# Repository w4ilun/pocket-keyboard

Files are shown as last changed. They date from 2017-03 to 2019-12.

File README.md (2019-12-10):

## Pocket Keyboard

First attempt at building a keyboard from scratch

* PCB Design and Fabrication - EasyEDA + Seeed
* EasyEDA Project [Link](https://easyeda.com/w4ilun/Pocket_Key-5001400dc132468eae7bc688ea3f74ed)
* Firmware - [TMK](https://github.com/tmk/tmk_keyboard)

Assembled

### Top Layer
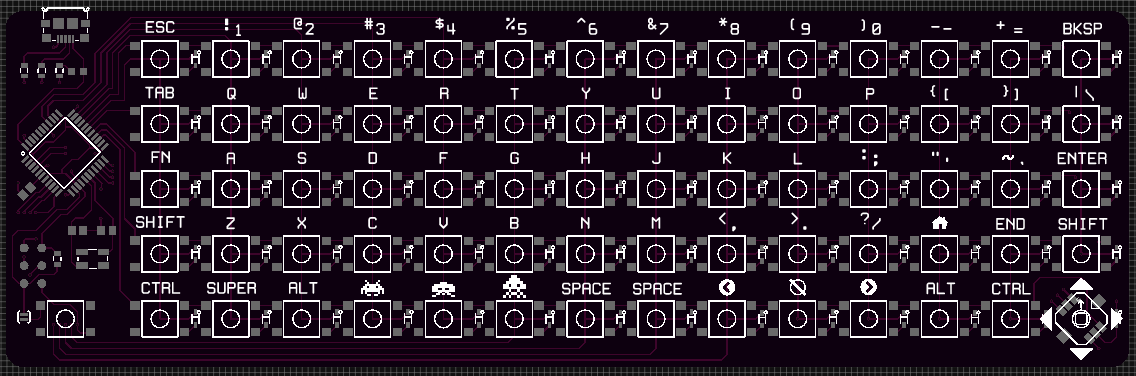
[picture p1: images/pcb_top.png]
Top Layer


### Bottom Layer
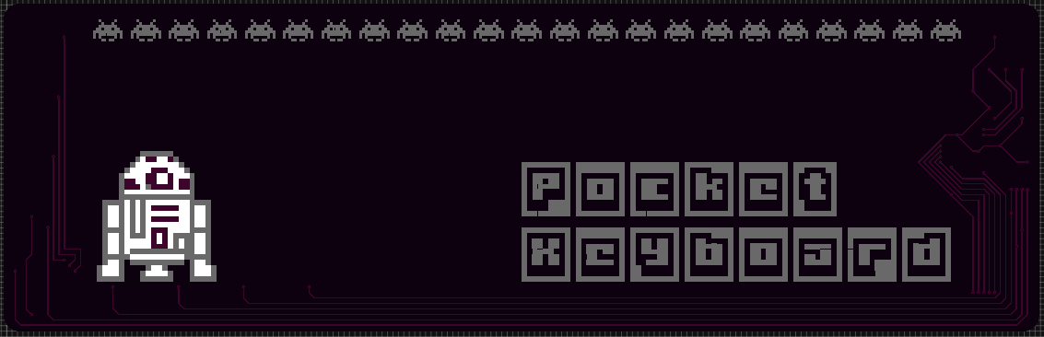
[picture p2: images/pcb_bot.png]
Bottom Layer


### PCB Layout
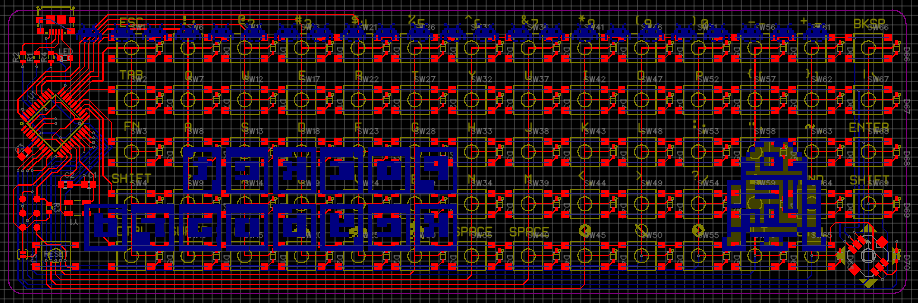
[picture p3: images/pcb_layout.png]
PCB Layout


### Components

| Component | Label  | Quantity |
| --- | --- | --- |
| Atmega32u4 | | 1 |
| 16MHZ Crystal | Y1 | 1 |
| Micro USB Connector | | 1 |
| 22OΩ | R1, R2 | 2 |
| 10KΩ | R3 | 1 |
| 330Ω | R4 | 1 |
| 22pF | C1, C2 | 2 |
| 1uF | C3 | 1 |
| LED | D0 | 1 |
| 1N4148 | D1-D70 | 70 |
| TL3303 Tactile Switch | SW | 70 |
| 5-way Switch | S1 | 1 |

### Schematic
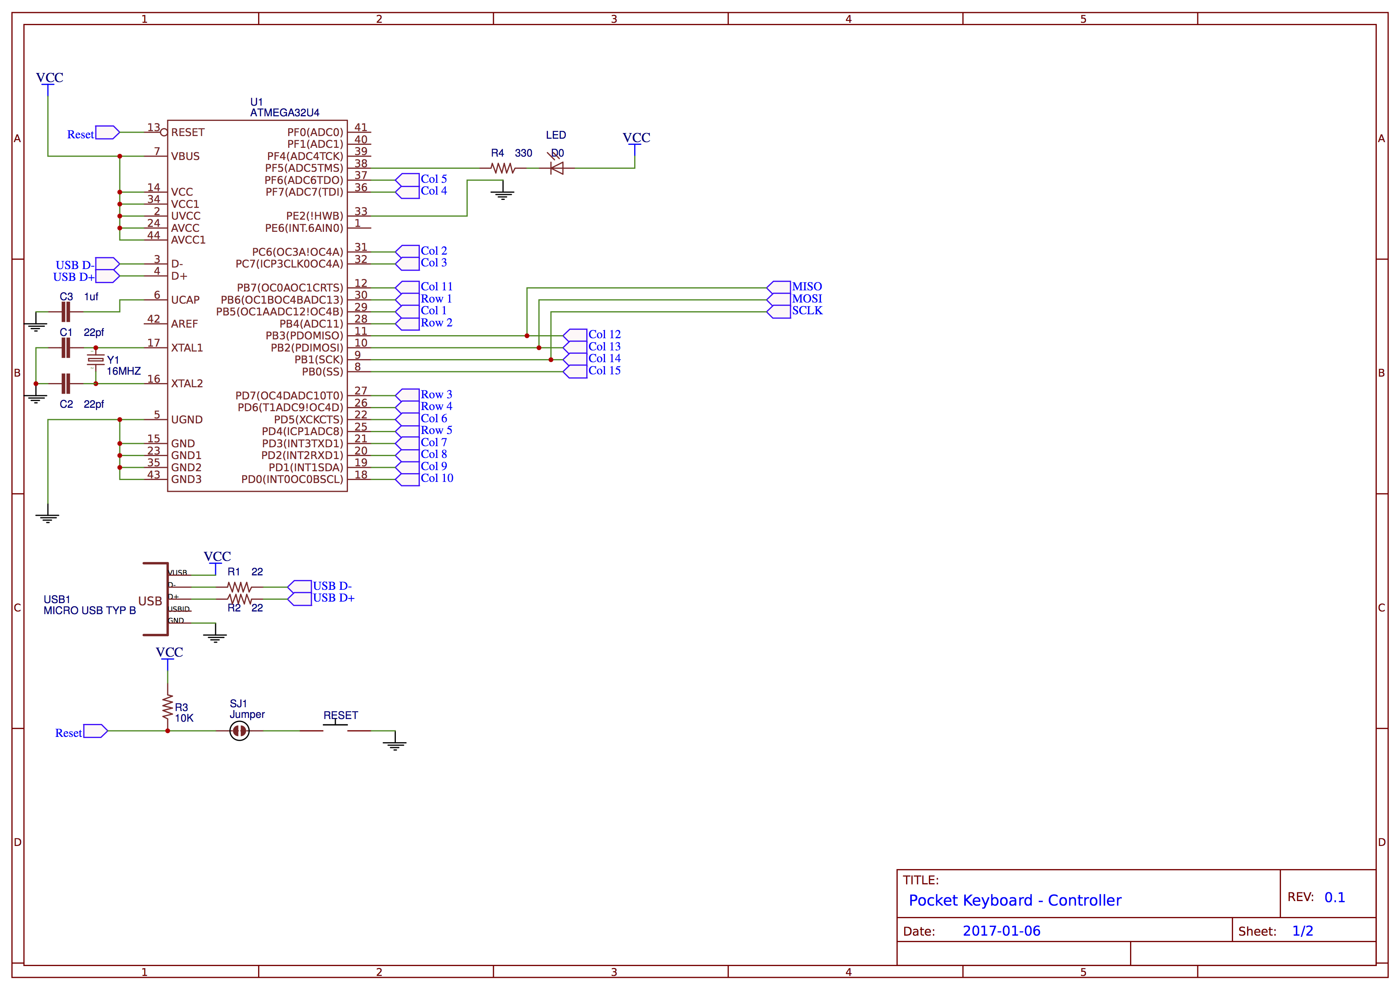
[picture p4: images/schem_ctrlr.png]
Controller

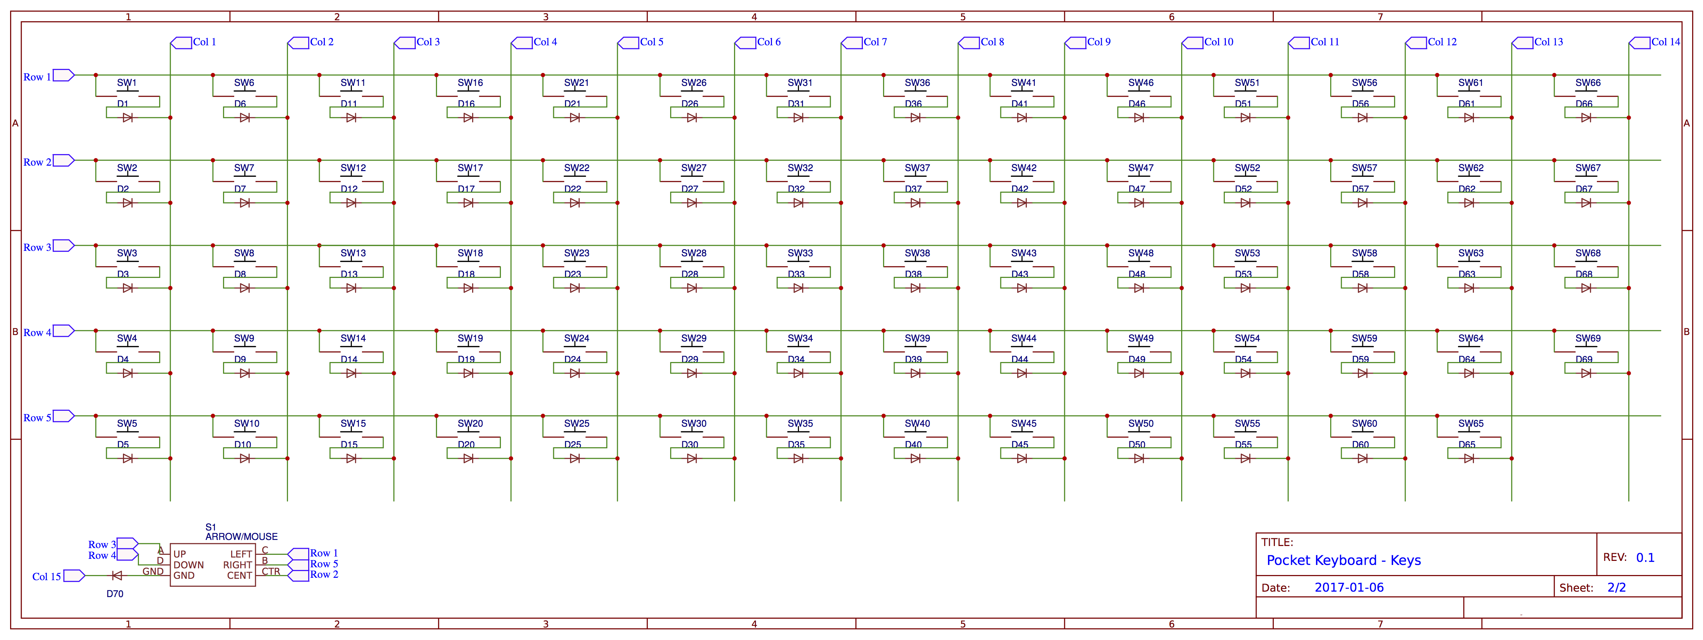
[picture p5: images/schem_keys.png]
Keys


### Firmware
* Based on [TMK](https://github.com/tmk/tmk_keyboard)'s onekey example
* `cd firmware/keyboard/pocket_kbd`
* `make -f Makefile`
* press the reset button
* `sudo dfu-programmer atmega32u4 erace --force --debug 5`
* `sudo dfu-programmer atmega32u4 flash firmware.hex --debug 5`
* power cycle board, it should now appear as an USB keyboard

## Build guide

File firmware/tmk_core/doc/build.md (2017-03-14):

Build Firmware and Program Controller
=====================================

Download and Install
--------------------
### 1. Install Tools

1. **Toolchain** On Windows install [Atmel AVR Toolchain][atmelgcc] for AVR GCC compiler and [Cygwin][cygwin](or [MinGW][mingw]) for shell terminal. On Mac you can use [CrossPack][crosspack] or your favorite package manager. On Linux you can install AVR GCC with your favorite package manager.

2. **Programmer** Install [dfu-programmer][dfu-prog]. GUI tool [Atmel FLIP][flip] also can be used on Windows.

3. **Driver** On Windows when you start DFU bootloader on the chip first time you will see **Found New Hardware Wizard** to install driver. If you install device driver properly you will find chip name like **ATmega32U4** under **LibUSB-Win32 Devices** tree on **Device Manager**. If not you shall need to update its driver on **Device Manager**. You will find the driver in `FLIP` install directory like: `C:\Program Files (x86)\Atmel\Flip 3.4.5\usb\`. In case of `dfu-programmer` install driver distributed with it.

If you use PJRC Teensy you don't need step 2 and 3 above, just get [Teensy loader][teensy-loader].

### 2. Download source
You can find firmware source at github:

- <https://github.com/tmk/tmk_keyboard>

If you are familiar with [`git`][git] tools you are recommended to use it but you can also download zip archive from:

- <https://github.com/tmk/tmk_keyboard/archive/master.zip>

Build firmware
--------------
### 1. Open terminal
Open terminal window to get access to commands. Use Cygwin(or MingGW) shell terminal in Windows or `Terminal.app` on Mac OSX.

### 2. Change directory
Move to project directory in the firmware source.

    cd tmk_keyboard/{'keyboard' or 'converter'}/<project>

### 3. Make
Build firmware using GNU `make` command. You'll see `<project>_<variant>.hex` file in that directory unless something unexpected occurs in build process.

    make -f Makefile.<variant> clean
    make -f Makefile.<variant>

Program Controller
------------------
Now you have **hex** file to program on current directory. This **hex** is only needed to program your controller, other files are used for development and you may leave and forget them.

### 1. Start bootloader
How to program controller depends on controller chip and its board design. To program AVR USB chips you'll need to start it up in bootloader mode. Most of boards with the chip have a push button to let bootloader come up. Consult with your controller board manual.

### 2. Program with DFU bootloader
Stock AVR USB chips have DFU bootloader by factory default. `FLIP` is a DFU programmer on Windows offered by Atmel. `FLIP` has two version of tool, GUI app and command line program. If you want GUI see tutorial below. Open source alternative `dfu-programmer` also supports AVR chips, it is command line tool and runs on Linux, Mac OSX and even Windows.

To program with command of `FLIP` run this. Note that you need to set PATH variable properly.

    $ make -f Makefile.<variant> flip

With `dfu-programmer` run this.

    $ make -f Makefile.<variant> dfu

Or you can execute the command directly as the following.

    $ dfu-programmer <controller> erase --force
    $ dfu-programmer <controller> flash <your_firmware.hex>
    $ dfu-programmer <controller> reset

`<controller>` part will be `atmega32u4` or `atmega32u2` in most cases. See manual of the command for the detail. On Linux and Mac OSX you will need proper permission to program a controller and you can use `sudo` command for this purpose probably. On Linux you also can configure `udev` rules to set permission.

#### FLIP GUI tutorial
1. On menu bar click **Device** -> **Select**, then choose your chip name. (In most cases **ATmega32U2** or **ATmega32U4**)
2. On menu bar click **Settings** -> **Communication** -> **USB**, then click **Open** button on **USB Port Connection** dialog. At this point you'll have to plug into USB and start bootloader.

3. On menu bar click **File** -> **Load HEX File**, then select your firmware hex file on File Selector dialog.
4. On **Operations Flow** panel click **Run** button to load the firmware binary to the chip. Note that you should keep **Erase**, **Blank Check**, **Program** and **Verify** check boxes selected.
5. Re-plug USB cord or click **Start Application** button to restart your controller.
Done.

See also these instructions if needed.

- <http://code.google.com/p/micropendous/wiki/LoadingFirmwareWithFLIP>
- <http://www.atmel.com/Images/doc7769.pdf>

##### Troubleshoot
* **FLIP: AtLibUsbDfu.dll not found**
Remove current driver and re-install one FLIP provides from DeviceManager of WIndows. See <http://imgur.com/a/bnwzy>

### 3. Program with Other programmer
If you are using PJRC Teensy consult with instruction of [Teensy Loader][teensy-loader]. Or run this target with `make` after you install command line version of it.

    $ make -f Makefile.<variant> teensy

You may want to use other programmer like [`avrdude`][avrdude]. In that case you can still use make target `program` for build with configuring `PROGRAM_CMD` in Makefile. See below.

    $ make -f Makefile.<variant> program

[atmelgcc]:     http://www.atmel.com/tools/ATMELAVRTOOLCHAINFORWINDOWS.aspx
[cygwin]:       https://www.cygwin.com/
[mingw]:        http://www.mingw.org/
[crosspack]:    http://www.obdev.at/products/crosspack/index.html
[flip]:         http://www.atmel.com/tools/FLIP.aspx
[dfu-prog]:     http://dfu-programmer.sourceforge.net/
[teensy-loader]:http://www.pjrc.com/teensy/loader.html
[avrdude]:      http://savannah.nongnu.org/projects/avrdude/
[git]:          https://git-scm.com/

Makefile Options
----------------
### 1. MCU and Frequency.

    MCU = atmega32u4       # Teensy 2.0
    #MCU = at90usb1286      # Teensy++ 2.0
    F_CPU = 16000000

Set your MCU and its clock in Hz.

    # Boot Section Size in *bytes*
    #   Teensy halfKay   512
    #   Teensy++ halfKay 2048
    #   Atmel DFU loader 4096
    #   LUFA bootloader  4096
    OPT_DEFS += -DBOOTLOADER_SIZE=4096

If you are using PJRC Teensy use `512` for `BOOTLOADER_SIZE`, otherwise use `4096` unless you are sure.

### 2. Features
Optional. Note that ***comment out*** with `#` to disable them.

    BOOTMAGIC_ENABLE = yes      # Virtual DIP switch configuration(+1000)
    MOUSEKEY_ENABLE = yes       # Mouse keys(+4700)
    EXTRAKEY_ENABLE = yes       # Audio control and System control(+450)
    CONSOLE_ENABLE = yes        # Console for debug(+400)
    COMMAND_ENABLE = yes        # Commands for debug and configuration
    SLEEP_LED_ENABLE = yes      # Breathing sleep LED during USB suspend
    #NKRO_ENABLE = yes          # USB Nkey Rollover - not yet supported in LUFA
    #BACKLIGHT_ENABLE = yes     # Enable keyboard backlight functionality

### 3. Programmer
Optional. Set proper command for your controller, bootloader and programmer. This command can be used with `make program`.

    # avrdude with AVRISPmkII
    PROGRAM_CMD = avrdude -p $(MCU) -c avrispmkII -P USB -U flash:w:$(TARGET).hex

    # avrdude with USBaspLoader
    PROGRAM_CMD = avrdude -p $(MCU) -c usbasp -U flash:w:$(TARGET).hex

    # avrdude with arduino
    PROGRAM_CMD = avrdude -p $(MCU) -c arduino -P COM1 -b 57600 -U flash:w:$(TARGET).hex

Config.h Options
----------------
### 1. Magic command key combination

    #define IS_COMMAND() (keyboard_report->mods == (MOD_BIT(KB_LSHIFT) | MOD_BIT(KB_RSHIFT)))

### 2. Mechanical Locking Support for CapsLock

    /* Mechanical locking CapsLock support. Use KC_LCAP instead of KC_CAPS in keymap */
    #define CAPSLOCK_LOCKING_ENABLE
    /* Locking CapsLock re-synchronize hack */
    #define CAPSLOCK_LOCKING_RESYNC_ENABLE

### 3. Disable Debug and Print

    /* disable debug print */
    #define NO_DEBUG

    /* disable print */
    #define NO_PRINT

### 4. Disable Action Features

    #define NO_ACTION_LAYER
    #define NO_ACTION_TAPPING
    #define NO_ACTION_ONESHOT
    #define NO_ACTION_MACRO
    #define NO_ACTION_FUNCTION

***TBD***

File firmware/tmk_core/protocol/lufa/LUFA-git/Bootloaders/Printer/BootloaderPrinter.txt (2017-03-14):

/** \file
 *
 *  This file contains special DoxyGen information for the generation of the main page and other special
 *  documentation pages. It is not a project source file.
 */

/** \mainpage Printer Class USB AVR Bootloader
 *
 *  \section Sec_Compat Demo Compatibility:
 *
 *  The following list indicates what microcontrollers are compatible with this demo.
 *
 *  \li Series 7 USB AVRs (AT90USBxxx7)
 *  \li Series 6 USB AVRs (AT90USBxxx6)
 *  \li Series 4 USB AVRs (ATMEGAxxU4)
 *  \li Series 2 USB AVRs (AT90USBxx2, ATMEGAxxU2)
 *
 *  \section Sec_Info USB Information:
 *
 *  The following table gives a rundown of the USB utilization of this demo.
 *
 *  <table>
 *   <tr>
 *    <td><b>USB Mode:</b></td>
 *    <td>Device</td>
 *   </tr>
 *   <tr>
 *    <td><b>USB Class:</b></td>
 *    <td>Printer Class</td>
 *   </tr>
 *   <tr>
 *    <td><b>USB Subclass:</b></td>
 *    <td>Printer Subclass</td>
 *   </tr>
 *   <tr>
 *    <td><b>Relevant Standards:</b></td>
 *    <td>USBIF Printer Class Standard</td>
 *   </tr>
 *   <tr>
 *    <td><b>Supported USB Speeds:</b></td>
 *    <td>Full Speed Mode</td>
 *   </tr>
 *  </table>
 *
 *  \section Sec_Description Project Description:
 *
 *  This bootloader enumerates to the host as a Generic Text Only Printer device, capable of reading and parsing
 *  "printed" plain-text Intel HEX files to load firmware onto the AVR.
 *
 *  Out of the box this bootloader builds for the AT90USB1287 with an 8KB bootloader section size, and will fit
 *  into 4KB of bootloader space. If you wish to alter this size and/or change the AVR model, you will need to
 *  edit the MCU, FLASH_SIZE_KB and BOOT_SECTION_SIZE_KB values in the accompanying makefile.
 *
 *  When the bootloader is running, the board's LED(s) will flash at regular intervals to distinguish the
 *  bootloader from the normal user application.
 *
 *  \section Sec_Running Running the Bootloader
 *
 *  This bootloader is designed to be started via the HWB mechanism of the USB AVRs; ground the HWB pin (see device
 *  datasheet) then momentarily ground /RESET to start the bootloader. This assumes the HWBE fuse is set and the BOOTRST
 *  fuse is cleared.
 *
 *  \section Sec_Installation Driver Installation
 *
 *  This bootloader uses the Generic Text-Only printer drivers inbuilt into all modern operating systems, thus no
 *  additional drivers need to be supplied for correct operation.
 *
 *  \section Sec_HostApp Host Controller Application
 *
 *  This bootloader is compatible with Notepad under Windows, and the command line \c lpr utility under Linux.
 *
 *  \subsection SSec_Notepad Notepad (Windows)
 *
 *  While most text applications under Windows will be compatible with the bootloader, the inbuilt Notepad utility
 *  is recommended as it will introduce minimal formatting changes to the output stream. To program with Notepad,
 *  open the target HEX file and print it to the Generic Text Only printer device the bootloader creates.
 *
 *  \subsection SSec_LPR LPR (Linux)
 *
 *  While the CUPS framework under Linux will enumerate the bootloader as a Generic Text-Only printer, many
 *  applications will refuse to print to the device due to the lack of rich formatting options available. As a result,
 *  under Linux HEX files must be printed via the low level \c lpr utility instead.
 *
 *  \code
 *  cat Mouse.hex | lpr
 *  \endcode
 *
 *  \section Sec_API User Application API
 *
 *  Several user application functions for FLASH and other special memory area manipulations are exposed by the bootloader,
 *  allowing the user application to call into the bootloader at runtime to read and write FLASH data.
 *
 *  By default, the bootloader API jump table is located 32 bytes from the end of the device's FLASH memory, and follows the
 *  following layout:
 *
 *  \code
 *  #define BOOTLOADER_API_TABLE_SIZE          32
 *  #define BOOTLOADER_API_TABLE_START         ((FLASHEND + 1UL) - BOOTLOADER_API_TABLE_SIZE)
 *  #define BOOTLOADER_API_CALL(Index)         (void*)((BOOTLOADER_API_TABLE_START + (Index * 2)) / 2)
 *
 *  void    (*BootloaderAPI_ErasePage)(uint32_t Address)               = BOOTLOADER_API_CALL(0);
 *  void    (*BootloaderAPI_WritePage)(uint32_t Address)               = BOOTLOADER_API_CALL(1);
 *  void    (*BootloaderAPI_FillWord)(uint32_t Address, uint16_t Word) = BOOTLOADER_API_CALL(2);
 *  uint8_t (*BootloaderAPI_ReadSignature)(uint16_t Address)           = BOOTLOADER_API_CALL(3);
 *  uint8_t (*BootloaderAPI_ReadFuse)(uint16_t Address)                = BOOTLOADER_API_CALL(4);
 *  uint8_t (*BootloaderAPI_ReadLock)(void)                            = BOOTLOADER_API_CALL(5);
 *  void    (*BootloaderAPI_WriteLock)(uint8_t LockBits)               = BOOTLOADER_API_CALL(6);
 *
 *  #define BOOTLOADER_MAGIC_SIGNATURE_START   (BOOTLOADER_API_TABLE_START + (BOOTLOADER_API_TABLE_SIZE - 2))
 *  #define BOOTLOADER_MAGIC_SIGNATURE         0xDCFB
 *
 *  #define BOOTLOADER_CLASS_SIGNATURE_START   (BOOTLOADER_API_TABLE_START + (BOOTLOADER_API_TABLE_SIZE - 4))
 *  #define BOOTLOADER_PRINTER_SIGNATURE       0xDF20
 *
 *  #define BOOTLOADER_ADDRESS_START           (BOOTLOADER_API_TABLE_START + (BOOTLOADER_API_TABLE_SIZE - 8))
 *  #define BOOTLOADER_ADDRESS_LENGTH          4
 *  \endcode
 *
 *  From the application the API support of the bootloader can be detected by reading the FLASH memory bytes located at address
 *  \c BOOTLOADER_MAGIC_SIGNATURE_START and comparing them to the value \c BOOTLOADER_MAGIC_SIGNATURE. The class of bootloader
 *  can be determined by reading the FLASH memory bytes located at address \c BOOTLOADER_CLASS_SIGNATURE_START and comparing them
 *  to the value \c BOOTLOADER_PRINTER_SIGNATURE. The start address of the bootloader can be retrieved by reading the bytes of FLASH
 *  memory starting from address \c BOOTLOADER_ADDRESS_START.
 *
 *  \subsection SSec_API_MemLayout Device Memory Map
 *  The following illustration indicates the final memory map of the device when loaded with the bootloader.
 *
 *  \verbatim
 *  +----------------------------+ 0x0000
 *  |                            |
 *  |                            |
 *  |                            |
 *  |                            |
 *  |                            |
 *  |                            |
 *  |                            |
 *  |                            |
 *  |      User Application      |
 *  |                            |
 *  |                            |
 *  |                            |
 *  |                            |
 *  |                            |
 *  |                            |
 *  |                            |
 *  +----------------------------+ FLASHEND - BOOT_SECTION_SIZE
 *  |                            |
 *  |   Bootloader Application   |
 *  | (Not User App. Accessible) |
 *  |                            |
 *  +----------------------------+ FLASHEND - 96
 *  |   API Table Trampolines    |
 *  | (Not User App. Accessible) |
 *  +----------------------------+ FLASHEND - 32
 *  |    Bootloader API Table    |
 *  |   (User App. Accessible)   |
 *  +----------------------------+ FLASHEND - 8
 *  |   Bootloader ID Constants  |
 *  |   (User App. Accessible)   |
 *  +----------------------------+ FLASHEND
 *  \endverbatim
 *
 *
 *  \section Sec_KnownIssues Known Issues:
 *
 *  \par On Linux machines, new firmware fails to be sent to the device via CUPS.
 *  Only a limited subset of normal printer functionality is exposed via the
 *  bootloader, causing CUPS to reject print requests from applications that
 *  are unable to handle true plain-text printing. For best results, the low
 *  level \c lpr command should be used to print new firmware to the bootloader.
 *
 *  \par After loading an application, it is not run automatically on startup.
 *  Some USB AVR boards ship with the BOOTRST fuse set, causing the bootloader
 *  to run automatically when the device is reset. In most cases, the BOOTRST
 *  fuse should be disabled and the HWBE fuse used instead to run the bootloader
 *  when needed.
 *
 *  \section Sec_Options Project Options
 *
 *  The following defines can be found in this demo, which can control the demo behaviour when defined, or changed in value.
 *
 *  <table>
 *   <tr>
 *    <td>
 *     None
 *    </td>
 *   </tr>
 *  </table>
 */

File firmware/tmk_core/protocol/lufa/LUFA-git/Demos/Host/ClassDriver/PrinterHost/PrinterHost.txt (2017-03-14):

/** \file
 *
 *  This file contains special DoxyGen information for the generation of the main page and other special
 *  documentation pages. It is not a project source file.
 */

/** \mainpage Printer Host Demo
 *
 *  \section Sec_Compat Demo Compatibility:
 *
 *  The following list indicates what microcontrollers are compatible with this demo.
 *
 *  \li Series 7 USB AVRs (AT90USBxxx7)
 *
 *  \section Sec_Info USB Information:
 *
 *  The following table gives a rundown of the USB utilization of this demo.
 *
 *  <table>
 *   <tr>
 *    <td><b>USB Mode:</b></td>
 *    <td>Host</td>
 *   </tr>
 *   <tr>
 *    <td><b>USB Class:</b></td>
 *    <td>Printer Device</td>
 *   </tr>
 *   <tr>
 *    <td><b>USB Subclass:</b></td>
 *    <td>Bidirectional Protocol</td>
 *   </tr>
 *   <tr>
 *    <td><b>Relevant Standards:</b></td>
 *    <td>USBIF Printer Class Specification \n
 *        PCL Language Specification</td>
 *   </tr>
 *   <tr>
 *    <td><b>Supported USB Speeds:</b></td>
 *    <td>Low Speed Mode \n
 *        Full Speed Mode</td>
 *   </tr>
 *  </table>
 *
 *  \section Sec_Description Project Description:
 *
 *  Printer host demonstration application. This gives a simple reference
 *  application for implementing a USB Printer host, for USB printers using
 *  the bidirectional data encapsulation protocol and PCL language.
 *
 *  Upon connection of a compatible printer, the printer's device ID is sent
 *  to the AVR's serial port, and a simple test page is printed using the PCL
 *  printer language.
 *
 *  \section Sec_Options Project Options
 *
 *  The following defines can be found in this demo, which can control the demo behaviour when defined, or changed in value.
 *
 *  <table>
 *   <tr>
 *    <td>
 *     None
 *    </td>
 *   </tr>
 *  </table>
 */

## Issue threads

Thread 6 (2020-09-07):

How do you add a bootloader to this PCB?

geocine, 2020-09-07:
Does this have a bootloader like the regular Pro Micro? Or, are there some specific steps to add bootloader to be able to enter DFU?

w4ilun, 2020-09-07:
From the factory it comes with DFU bootloader, so you can upload your firmware using DFU right away. If you would like an "Arduino" bootloader (i.e. Pro Micro - over serial), then you can use an ISP flasher to update it

Closed 2020-09-08.

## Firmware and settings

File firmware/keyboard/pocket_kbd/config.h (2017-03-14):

/*
Copyright 2012 Jun Wako <wakojun@gmail.com>

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
You should have received a copy of the GNU General Public License
along with this program.  If not, see <http://www.gnu.org/licenses/>.
*/

#ifndef CONFIG_H
#define CONFIG_H


/* USB Device descriptor parameter */
#define VENDOR_ID       0xDEAD
#define PRODUCT_ID      0xBEEF
#define DEVICE_VER      0x0001
#define MANUFACTURER    w4ilun
#define PRODUCT         pocketkb
#define DESCRIPTION     Pocket Keyboard by w4ilun

/* key matrix size */
#define MATRIX_ROWS 5
#define MATRIX_COLS 15

/* define if matrix has ghost */
//#define MATRIX_HAS_GHOST

/* Set 0 if debouncing isn't needed */
#define DEBOUNCE    5

/* Mechanical locking support. Use KC_LCAP, KC_LNUM or KC_LSCR instead in keymap */
#define LOCKING_SUPPORT_ENABLE
/* Locking resynchronize hack */
#define LOCKING_RESYNC_ENABLE

/* key combination for command */
#define IS_COMMAND() ( \
    keyboard_report->mods == (MOD_BIT(KC_LSHIFT) | MOD_BIT(KC_RSHIFT)) \
)



/*
 * Feature disable options
 *  These options are also useful to firmware size reduction.
 */

/* disable debug print */
//#define NO_DEBUG

/* disable print */
//#define NO_PRINT

/* disable action features */
//#define NO_ACTION_LAYER
//#define NO_ACTION_TAPPING
//#define NO_ACTION_ONESHOT
//#define NO_ACTION_MACRO
//#define NO_ACTION_FUNCTION


/* PS/2 mouse */
#ifdef PS2_USE_BUSYWAIT
#   define PS2_CLOCK_PORT  PORTD
#   define PS2_CLOCK_PIN   PIND
#   define PS2_CLOCK_DDR   DDRD
#   define PS2_CLOCK_BIT   1
#   define PS2_DATA_PORT   PORTD
#   define PS2_DATA_PIN    PIND
#   define PS2_DATA_DDR    DDRD
#   define PS2_DATA_BIT    2
#endif


/* PS/2 mouse interrupt version */
#ifdef PS2_USE_INT
/* uses INT1 for clock line(ATMega32U4) */
#define PS2_CLOCK_PORT  PORTD
#define PS2_CLOCK_PIN   PIND
#define PS2_CLOCK_DDR   DDRD
#define PS2_CLOCK_BIT   1
#define PS2_DATA_PORT   PORTD
#define PS2_DATA_PIN    PIND
#define PS2_DATA_DDR    DDRD
#define PS2_DATA_BIT    2

#define PS2_INT_INIT()  do {    \
    EICRA |= ((1<<ISC11) |      \
              (0<<ISC10));      \
} while (0)
#define PS2_INT_ON()  do {      \
    EIMSK |= (1<<INT1);         \
} while (0)
#define PS2_INT_OFF() do {      \
    EIMSK &= ~(1<<INT1);        \
} while (0)
#define PS2_INT_VECT    INT1_vect
#endif


/* PS/2 mouse USART version */
#ifdef PS2_USE_USART
#if defined(__AVR_ATmega16U4__) || defined(__AVR_ATmega32U4__)
/* XCK for clock line and RXD for data line */
#define PS2_CLOCK_PORT  PORTD
#define PS2_CLOCK_PIN   PIND
#define PS2_CLOCK_DDR   DDRD
#define PS2_CLOCK_BIT   5
#define PS2_DATA_PORT   PORTD
#define PS2_DATA_PIN    PIND
#define PS2_DATA_DDR    DDRD
#define PS2_DATA_BIT    2

/* synchronous, odd parity, 1-bit stop, 8-bit data, sample at falling edge */
/* set DDR of CLOCK as input to be slave */
#define PS2_USART_INIT() do {   \
    PS2_CLOCK_DDR &= ~(1<<PS2_CLOCK_BIT);   \
    PS2_DATA_DDR &= ~(1<<PS2_DATA_BIT);     \
    UCSR1C = ((1 << UMSEL10) |  \
              (3 << UPM10)   |  \
              (0 << USBS1)   |  \
              (3 << UCSZ10)  |  \
              (0 << UCPOL1));   \
    UCSR1A = 0;                 \
    UBRR1H = 0;                 \
    UBRR1L = 0;                 \
} while (0)
#define PS2_USART_RX_INT_ON() do {  \
    UCSR1B = ((1 << RXCIE1) |       \
              (1 << RXEN1));        \
} while (0)
#define PS2_USART_RX_POLL_ON() do { \
    UCSR1B = (1 << RXEN1);          \
} while (0)
#define PS2_USART_OFF() do {    \
    UCSR1C = 0;                 \
    UCSR1B &= ~((1 << RXEN1) |  \
                (1 << TXEN1));  \
} while (0)
#define PS2_USART_RX_READY      (UCSR1A & (1<<RXC1))
#define PS2_USART_RX_DATA       UDR1
#define PS2_USART_ERROR         (UCSR1A & ((1<<FE1) | (1<<DOR1) | (1<<UPE1)))
#define PS2_USART_RX_VECT       USART1_RX_vect
#endif
#endif

#endif

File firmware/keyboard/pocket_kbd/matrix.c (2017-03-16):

/*
Copyright 2012 Jun Wako <wakojun@gmail.com>

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
You should have received a copy of the GNU General Public License
along with this program.  If not, see <http://www.gnu.org/licenses/>.
*/

/*
 * scan matrix
 */
#include <stdint.h>
#include <stdbool.h>
#include <avr/io.h>
#include <util/delay.h>
#include "print.h"
#include "debug.h"
#include "util.h"
#include "matrix.h"


#ifndef DEBOUNCE
#   define DEBOUNCE 5
#endif
static uint8_t debouncing = DEBOUNCE;

/* matrix state(1:on, 0:off) */
static matrix_row_t matrix[MATRIX_ROWS];
static matrix_row_t matrix_debouncing[MATRIX_ROWS];

static matrix_row_t read_cols(void);
static void init_cols(void);
static void unselect_rows(void);
static void select_row(uint8_t row);


void matrix_init(void)
{   
    debug_enable = true;
    // initialize row and col
    unselect_rows();
    init_cols();

    // initialize matrix state: all keys off
    for (uint8_t i=0; i < MATRIX_ROWS; i++) {
        matrix[i] = 0;
        matrix_debouncing[i] = 0;
    }
}

uint8_t matrix_scan(void)
{
    for (uint8_t i = 0; i < MATRIX_ROWS; i++) {
        select_row(i);
        _delay_us(30);  // without this wait read unstable value.
        matrix_row_t cols = read_cols();
        if (matrix_debouncing[i] != cols) {
            matrix_debouncing[i] = cols;
            if (debouncing) {
                debug("bounce!: "); debug_hex(debouncing); debug("\n");
            }
            debouncing = DEBOUNCE;
        }
        unselect_rows();
    }

    if (debouncing) {
        if (--debouncing) {
            _delay_ms(1);
        } else {
            for (uint8_t i = 0; i < MATRIX_ROWS; i++) {
                matrix[i] = matrix_debouncing[i];
            }
        }
    }

    return 1;
}

inline
matrix_row_t matrix_get_row(uint8_t row)
{
    return matrix[row];
}

/* Column pin configuration
 * col: 0  1  2  3  4  5  6  7  8  9  10  11  12  13  14
 * pin: B5 C6 C7 F7 F6 D5 D3 D2 D1 D0 B7  B3  B2  B1  B0
 */
static void  init_cols(void)
{
    // Input with pull-up(DDR:0, PORT:1)
    DDRB  &= ~(1<<0 | 1<<1 | 1<<2 | 1<<3 | 1<<5 | 1<<7);
    PORTB |=  (1<<0 | 1<<1 | 1<<2 | 1<<3 | 1<<5 | 1<<7);
    DDRC  &= ~(1<<6 | 1<<7);
    PORTC |=  (1<<6 | 1<<7);
    DDRD  &= ~(1<<5 | 1<<3 | 1<<2 | 1<<1 | 1<<0);
    PORTD |=  (1<<5 | 1<<3 | 1<<2 | 1<<1 | 1<<0);
    DDRF  &= ~(1<<6 | 1<<7);
    PORTF |=  (1<<6 | 1<<7);    
}

static matrix_row_t read_cols(void)
{
    return (PINB&(1<<5) ? 0 : (1<<0)) |
           (PINC&(1<<6) ? 0 : (1<<1)) |
           (PINC&(1<<7) ? 0 : (1<<2)) |
           (PINF&(1<<7) ? 0 : (1<<3)) |
           (PINF&(1<<6) ? 0 : (1<<4)) |
           (PIND&(1<<5) ? 0 : (1<<5)) |
           (PIND&(1<<3) ? 0 : (1<<6)) |
           (PIND&(1<<2) ? 0 : (1<<7)) |
           (PIND&(1<<1) ? 0 : (1<<8)) |
           (PIND&(1<<0) ? 0 : (1<<9)) |
           (PINB&(1<<7) ? 0 : (1<<10)) |
           (PINB&(1<<3) ? 0 : (1<<11)) |
           (PINB&(1<<2) ? 0 : (1<<12)) |
           (PINB&(1<<1) ? 0 : (1<<13)) |
           (PINB&(1<<0) ? 0 : (1<<14));
}

/* Row pin configuration
 * row: 0   1   2   3   4
 * pin: B6  B4  D7  D6  D4
 */

static void unselect_rows(void)
{
    // Hi-Z(DDR:0, PORT:0) to unselect
    DDRB  &= ~0b01010000;
    PORTB &= ~0b01010000;
    DDRD  &= ~0b11010000;
    PORTD &= ~0b11010000;    
}

static void select_row(uint8_t row)
{
    // Output low(DDR:1, PORT:0) to select
    switch (row) {
        case 0:
            DDRB  |= (1<<6);
            PORTB &= ~(1<<6);
            break;
        case 1:
            DDRB  |= (1<<4);
            PORTB &= ~(1<<4);
            break;
        case 2:
            DDRD  |= (1<<7);
            PORTD &= ~(1<<7);
            break;
        case 3:
            DDRD  |= (1<<6);
            PORTD &= ~(1<<6);
            break;
        case 4:
            DDRD  |= (1<<4);
            PORTD &= ~(1<<4);
            break;
    }    
}

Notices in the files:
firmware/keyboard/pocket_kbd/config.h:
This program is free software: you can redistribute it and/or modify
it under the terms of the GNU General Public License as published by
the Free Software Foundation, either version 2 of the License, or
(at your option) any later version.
